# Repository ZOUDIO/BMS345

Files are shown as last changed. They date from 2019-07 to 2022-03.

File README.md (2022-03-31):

# BMS345
Protection and charging module for 3/4/5S lithium batteries 
This project is fully open-source and may be used commercially.
ZOUDIO is only liable for products of its own production.

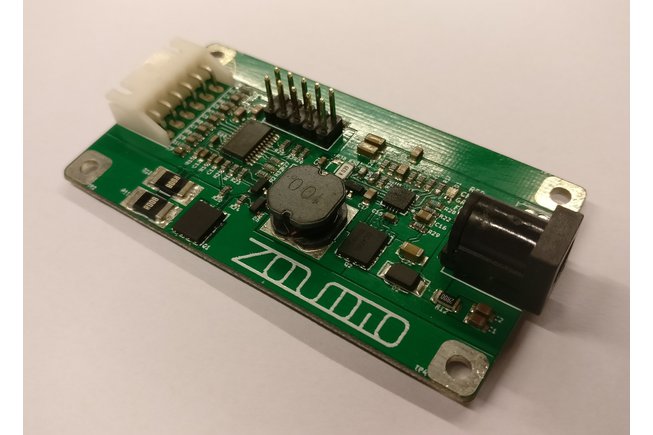
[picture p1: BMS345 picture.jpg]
Picture of the BMS345


Based on:
Texas Instruments BQ77915 primary battery protector
Texas Instruments BQ24650 battery charger

Configuration is set by using the onboard header. 

Specifications (for more details and instructions, refer to the PDF datasheet)
-	Overvoltage:				4.2V ±10mV, delay 1S
-	Undervoltage: 			2.9V ±18mV, delay 1S
-	Cell balancing 			4mA per cell
-	Maximum continuous discharge:	10A
-	Overcurrent protection: 		15A, delay 180mS
-	Short-circuit protection: 		30A, delay 1mS
-	Recovery after fault event: 		Attach charger
-	Open cell/wire detection:		4.5S delay
-	Power consumption: 			8μA typical
-	Charging current:			1A
-	Charging voltage:			4.05V per cell
-	MPPT voltage:			17.5V
-	Operating temperature: 		-40 to 85 °C
-	Dimensions (WxHxD):		71x38x15mm

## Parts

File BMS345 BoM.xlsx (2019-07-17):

Quantity | Designator | Package | Type | Value | MPFN
1 | U1 | SMD, QFN16 |  |  | BQ24650RVAR
1 | U2 | SMD, TSSOP-24 |  |  | BQ7791500PWR
2 | Q1,Q2 | SMD, SO8FL-dual | Dual NMOS |  | NVMFD5C466NLT1G
1 | D1 | SMD, 1.6x1.25mm | Bicolor LED | RED/GREEN | KPTB-1612SURKCGKC
1 | D2 | SMD, SOD-128 | Schottky |  | PMEG4050EP,115
2 | D3,D4 | SMD, SOT-23 | Schottky |  | BAT54C-7-F
1 | D5 | SMD, SOT-23 | Zener | 10V | BZX84C10LT1G
1 | L1 | SMD, 10x10mm | Shielded | 10u | SRN1060-100M
2 | R11,R16 | SMD, 2512 | 1% or better | 8m | MRF6432(2512)LR008FTS
1 | R30 | SMD, 1206 | 1% or better | 39m | STE1206M1W0R039F
1 | R12 | SMD, 1206 | 1% or better | 2R | 1206W4F200KT5E
1 | R29 | SMD, 0603 | 1% or better | 10R | 0603WAF100JT5E
2 | R15,R19 | SMD, 0603 | 1% or better | 100R | 0603WAF1000T5E
7 | R4,R5,R6,R7,R8,R9,R10 | SMD, 0603 | 1% or better | 1K | 0603WAF1001T5E
9 | R1,R3,R13,R14,R17,R18,R21,R25,R26 | SMD, 0603 | 1% or better | 10K | 0603WAF1002T5E
1 | R28 | SMD, 0603 | 1% or better | 75K | 0603WAF7502T5E
3 | R27,R33,R39 | SMD, 0603 | 1% or better | 100k | 0603WAF1003T5E
3 | R34,R35,R37 | SMD, 0603 | 1% or better | 249k | 0603WAF2493T5E
6 | R2,R20,R22,R23,R31,R32 | SMD, 0603 | 1% or better | 1M | 0603WAF1004T5E
1 | R24 | SMD, 0603 | 1% or better | 3M3 | 0603WAF3304T5E
1 | R36 | SMD, 0603 | 1% or better | 22M | RTT032205FTP
1 | C20 | SMD, 0603 | X5R and +/-20% or better, 50V+ | 18p | CC0603JRNPO9BN180
11 | C4,C5,C6,C7,C8,C9,C10,C11,C12,C15,C21 | SMD, 0603 | X5R and +/-20% or better, 50V+ | 100n | CC0603KRX7R9BB104
8 | C1,C2,C3,C13,C14,C16,C17,C19 | SMD, 0805 | X5R and +/-20% or better, 50V+ | 1u | CL21B105KBFNNNE
3 | C18,C22,C23 | SMD, 1206 | X5R and +/-20% or better, 50V+ | 10u | CL31B106KBHNNNE
1 | J1 | TH, 2.54mm pinheader | 2x5P |  | Z-21310110021001
All following components are Do Not Place (DNP):
DNP | R38 | SMD, 1206
DNP | J2 | TH, JSTXH_6P
DNP | J3 | TH, DC Jack
DNP | J4 | TH, JSTPH_3P
DNP | J5 | TH, Pinheader 1x2
DNP | Logo1 | Silkscreen logo
DNP | TP1, TP2, TP3, TP4 | Solderpad

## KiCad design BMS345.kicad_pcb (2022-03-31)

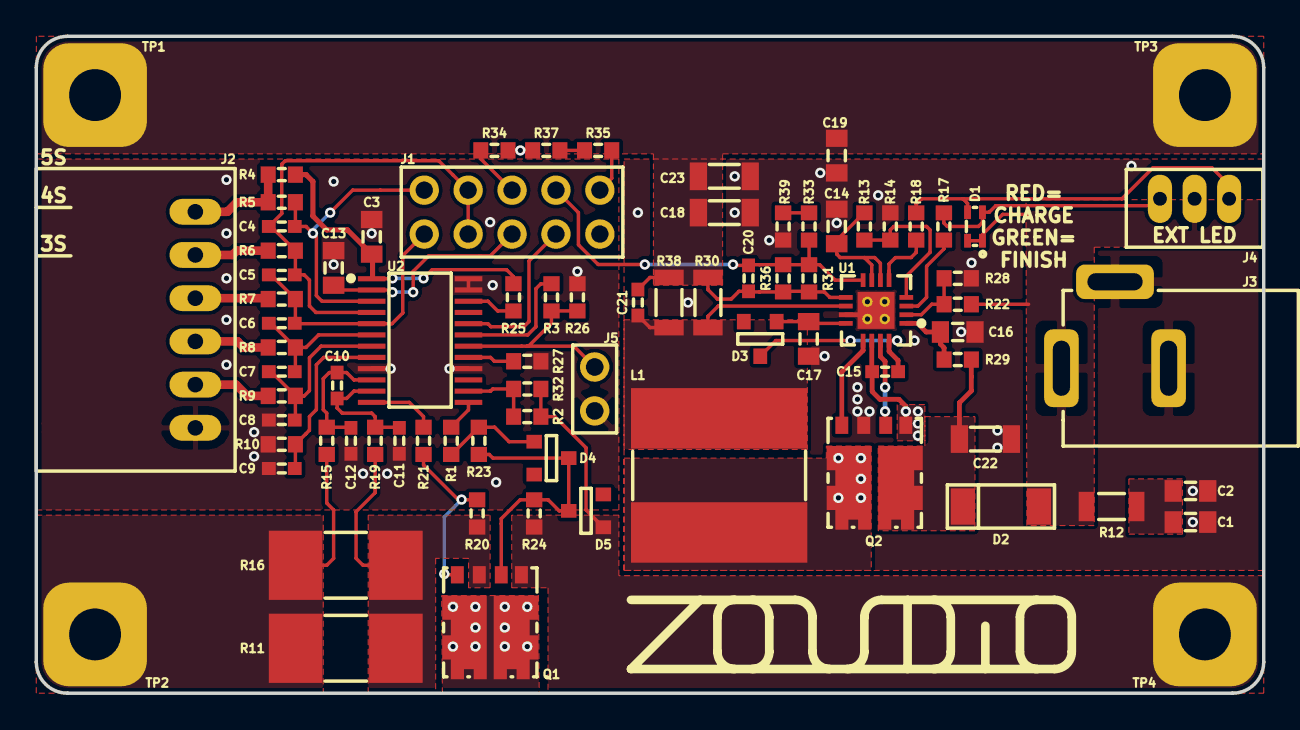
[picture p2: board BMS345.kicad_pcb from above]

Board: 2 copper layers, 71.0 x 38.0 mm, 82 parts (0 on the bottom side), 54 nets.

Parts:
C1, C2, C3, C13, C14, C16, C17, C19: 1u; C0805
C4, C5, C6, C7, C8, C9, C10, C11, C12, C15, C21: 100n; C0603
C18, C22, C23: 10u; C1206
C20: 18p; C0603
D1: RED/GREEN; KingBright_KPTB
D2: Schottky; SOD-128
D3, D4: Schottky; SOT-23Z
D5: 10V; SOT-23Z
J1: CONFIG; PinHeader_2x05_P2.54mm_Vertical
J2: BATT; JSTXH_S6B
J3: DC Jack; DC_Jack
J4: EXTLED; JSTPH_3P
J5: NTC; 2P_2.54mm_header
L1: 10u; SRN1060
Logo1: ZOUDIO; ZOUDIO25mm
Q1, Q2: NMOS; SO8FLDual
R1, R3, R17, R18, R21, R25, R26: 10k; R0603
R2, R20, R22, R23, R31, R32: 1M; R0603
R4, R5, R6, R7, R8, R9, R10: 1K; R0603
R11, R16: 8m; R2512SNS
R12: 2R; R1206
R13, R14: 10K; R0603
R15, R19: 100R; R0603
R24: 3M3; R0603
R27, R33, R39: 100k; R0603
R28: 75K; R0603
R29: 10R; R0603
R30, R38: 39m; R1206
R34, R35, R37: 249k; R0603
R36: 33M; R0603
TP1: BATT+; Pad_6mm
TP2: BATT-; Pad_6mm
TP3: PACK+; Pad_6mm
TP4: PACK-; Pad_6mm
U1: BQ24650; QFN16
U2: BQ77915; TSSOP-24

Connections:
+24V: D1.1, D1.3, D2.2, J3.1, J4.2, R12.2, R22.2
/AVDD: C13.1, J1.6, U2.2
/BATT-: R11.2, R15.1, R16.2, TP2.1
/CCFG: J1.4, U2.20
/PACK+: C18.1, C19.2, C20.1, C21.2, C23.1, R30.2, R31.2, R36.2, R38.2, TP1.1, TP3.1, U1.9
/TS: R13.1, R14.2, U1.4
/VC3: C5.2, C6.1, J1.10, R7.1, U2.5
/VC4: C4.2, C5.1, J1.7, J1.8, R6.1, U2.4
/VC5: C4.1, J1.9, R5.1, U2.3
/VFB: C20.2, J1.3, R31.1, R33.2, R36.1, U1.8
/VREF: C14.2, R13.2, U1.6, U1.7
GND: C3.2, C8.2, C9.1, C11.1, C12.2, C13.2, J1.2, J2.1, J5.2, R10.2, R26.1, R27.1, U2.9, U2.16, U2.23, U2.24
GNDPWR: C1.1, C2.1, C14.1, C16.2, C17.2, C18.2, C19.1, C22.2, C23.2, D5.2, J3.2, J3.3, Q1.5, Q2.2, R2.1, R14.1, R24.1, R28.1, R32.1, R34.2, R37.2, R39.1, TP4.1, U1.11, U1.17
unnamed: C1.2, C2.2, R12.1
unnamed: C3.1, R4.1, R25.1, U2.1
unnamed: C6.2, C7.1, R8.1, U2.6
unnamed: C7.2, C8.1, R9.1, U2.7
unnamed: C9.2, R10.1, U2.8
unnamed: C10.1, C11.2, R19.2, U2.11
unnamed: C10.2, C12.1, R15.2, U2.10
unnamed: C15.1, D3.1, U1.16
unnamed: C15.2, L1.1, Q2.4, Q2.5, U1.14
unnamed: C16.1, R29.1, U1.1
unnamed: C17.1, D3.2, U1.12
unnamed: C21.1, L1.2, R30.1, R38.1, U1.10
unnamed: C22.1, D2.1, Q2.6, R29.2
unnamed: D1.2, J4.3, R17.2
unnamed: D1.4, J4.1, R18.2
unnamed: D4.1, D5.1, Q1.1, R23.1, R24.2
unnamed: D4.2, R1.1, R23.2
unnamed: J1.1, R35.1
unnamed: J1.5, R34.1
unnamed: J2.2, R9.2
unnamed: J2.3, R8.2
unnamed: J2.4, R7.2
unnamed: J2.5, R6.2
unnamed: J2.6, R4.2, R5.2
unnamed: J5.1, R3.1, R26.2, U2.18
unnamed: Q1.2, R11.1, R16.1, R19.1, R20.1
unnamed: Q1.3, R20.2, R21.1
unnamed: Q1.4, Q1.6
unnamed: Q2.1, U1.15
unnamed: Q2.3, U1.13
unnamed: R1.2, U2.13
unnamed: R2.2, R32.2, U2.14
unnamed: R3.2, U2.19
unnamed: R17.1, U1.3
unnamed: R18.1, U1.5
unnamed: R21.2, U2.12
unnamed: R22.1, R28.2, U1.2
unnamed: R25.2, U2.22
unnamed: R27.2, U2.17
unnamed: R33.1, R39.2
unnamed: R35.2, R37.1

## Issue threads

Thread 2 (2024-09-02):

Mosfet pinout incorrect?

madhunm, 2024-09-02:
The MOSFET pinout in the schematic seems incorrect.

According to the NVMFD5C466NL datasheet (https://www.onsemi.com/pdf/datasheet/nvmfd5c466nl-d.pdf), the pinout is as follows:

Pin 1: Source pin of first MOSFET
Pin 2: Gate pin of first MOSFET
Pin 3: Source pin of second MOSFET
Pin 4: Gate pin of second MOSFET
Pin 5, 6: Drain pin of second MOSFET
Pin 7, 8: Drain pin of first MOSFET

In your schematic, the MOSFET pinout for both sections are as follows:

Pin 1: Gate pin of first MOSFET
Pin 2: Source pin of second MOSFET
Pin 3: Gate pin of second MOSFET
Pin 4: Drain pin of second MOSFET
Pin 5: Source pin of first MOSFET
Pin 6: Drain pin of first MOSFET

If you have used a MOSFET with a different pin configuration, please share that part number.

Thanks!

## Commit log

2019-07-17 Added design files and datasheet
    [BMS345V0.9 BoM.xlsx, BMS345V2.kicad_pcb, BMS345V2.sch]
2019-07-17 Create gerber description
2019-07-17 Add gerber and PnP files
    [BMS345v0.9 pickandplace.csv]
2022-03-31 Rename and fix symbol library reference
    Remove version number from names
    Fix symbol library references so schematic does not break for future viewers.
    Footprint library is still a mess, but they are cached in the layout, so it matters less.
    [BMS345 BoM.xlsx, BMS345.kicad_pcb, BMS345.sch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]
